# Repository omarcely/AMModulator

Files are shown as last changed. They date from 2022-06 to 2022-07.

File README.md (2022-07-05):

# AMModulator
Final RF circuits' project of Omar Cely, Diego Figueroa and Felipe González

## Resultados 

A continuación se puede observar el transmisor AM, y observar los resultados del circuito implementado en cada una de las etapas de interés.

## transmisor AM

En el montaje final se observa principalmente la antena, cuyo diametro es de 44 cm y tiene 3 vueltas, además se ve la pequeña placa que implementa el oscilador y el mezclador que mide 5cm x 2.5cm.

WhatsApp Image 2022-07-05 at 17 14 21

### Salida del oscilador

salida del oscilador medida con el analizador de espectros, como se puede ver se tiene una frecuencia de oscilación de 27.6 MHz aproximadamente, sin embargo la frecuencoa es ajustable por medio del inductor variable utilizado.

WhatsApp Image 2022-07-05 at 17 06 35

### Salida del mezclador

salida del mezcaldor medida con un analizador de espectros, y teniendo como mensaje una señal de 15kHz, como resultado se observa la portadora, y varios armónicos del mensaje en las bandas lateralres, podria ser bueno utilizar un filtro pasa bandas para mejorar el desempeño del mezclador

WhatsApp Image 2022-07-05 at 17 08 02

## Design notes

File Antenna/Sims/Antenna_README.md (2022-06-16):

# AMModulator
Final RF circuits' project of Omar Cely, Diego Figueroa and Felipe González

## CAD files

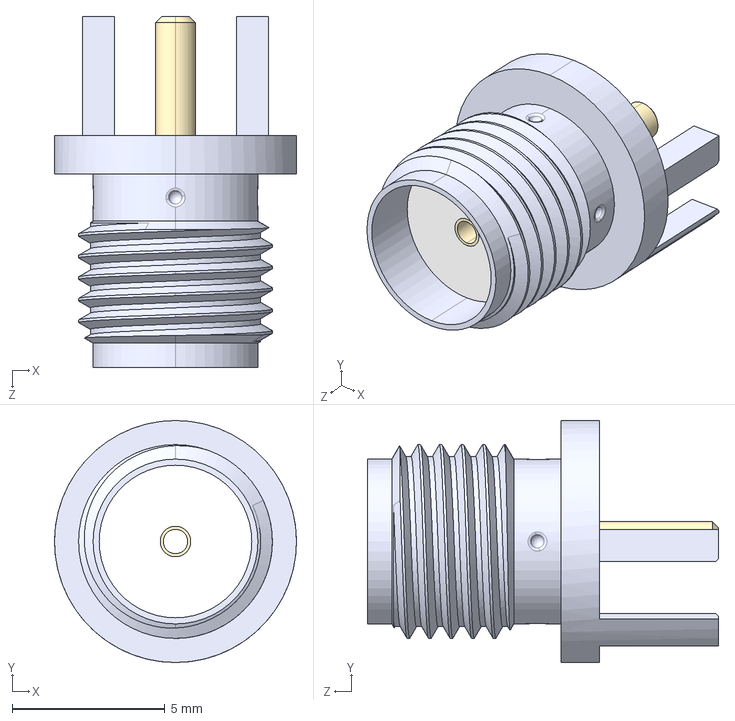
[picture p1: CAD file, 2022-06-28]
PCB design/AM_modulator/SMA/CONSMA003.062/CONSMA003.062.step
7.93 x 7.93 x 11.5 mm

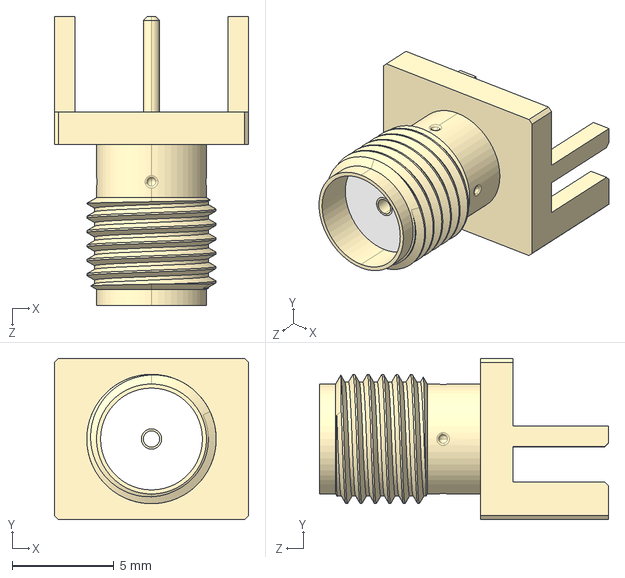
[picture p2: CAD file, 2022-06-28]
PCB design/AM_modulator/SMA/SMA/CONSMA020.062-G.step
9.52 x 7.92 x 14.2 mm

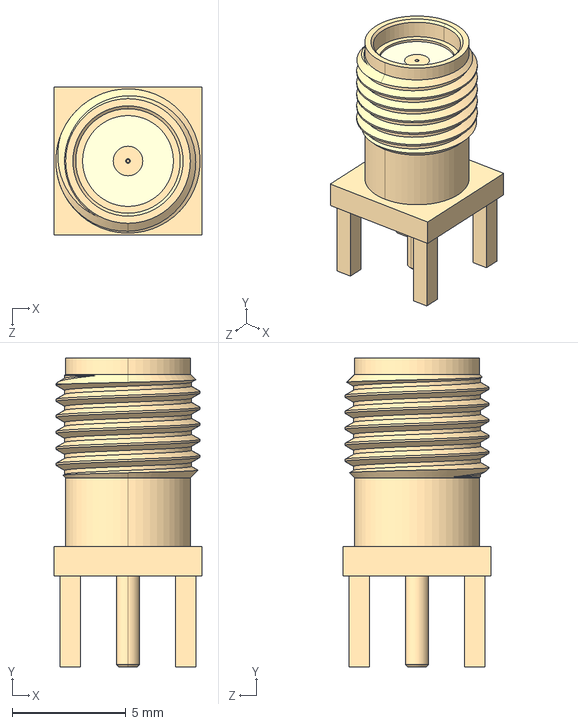
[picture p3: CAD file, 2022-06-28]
PCB design/AM_modulator/SMA/SMA_2/SMA_CONNECTOR.step
6.50 x 13.6 x 6.50 mm

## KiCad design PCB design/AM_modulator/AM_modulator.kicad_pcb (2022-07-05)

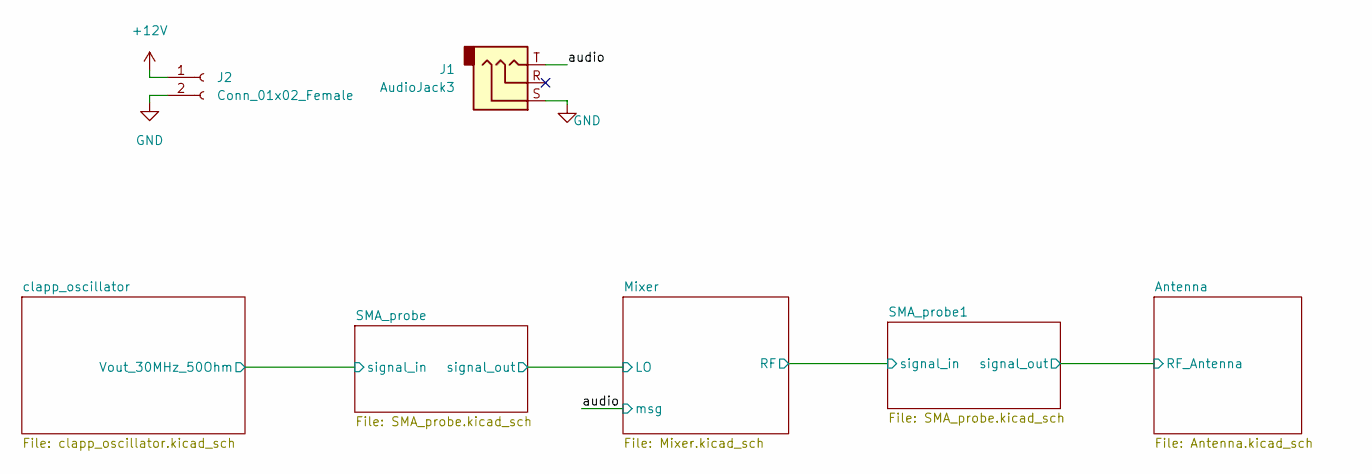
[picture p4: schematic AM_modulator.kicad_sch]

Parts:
J1: AudioJack3; Jack_Sigma
J2: Conn_01x02_Female; PinSocket_1x02_P2.54mm_Vertical

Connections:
+12V: J2.1; also elsewhere on the board
/audio: J1.T; also elsewhere on the board
GND: J1.S, J2.2; also elsewhere on the board

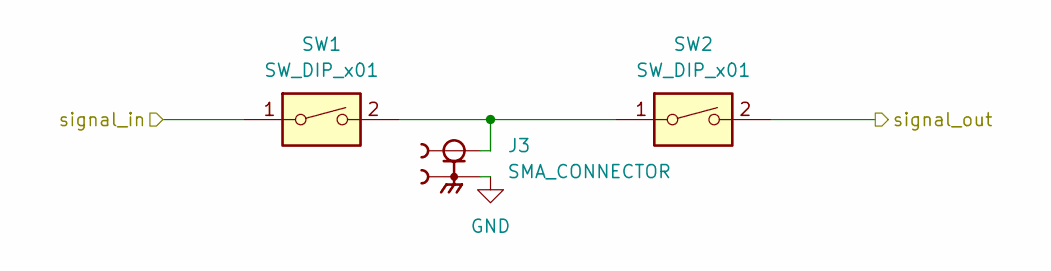
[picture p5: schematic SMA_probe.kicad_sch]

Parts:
J3: SMA_CONNECTOR; LPRS_SMA_CONNECTOR; PARTREV 1.3
SW1, SW2: SW_DIP_x01; R_1206_3216Metric

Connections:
/Mixer/LO: SW2.2; also elsewhere on the board
/SMA_probe/signal_in: SW1.1; also elsewhere on the board
GND: J3.G1, J3.G2, J3.G3, J3.G4; also elsewhere on the board
unnamed: J3.1, SW1.2, SW2.1

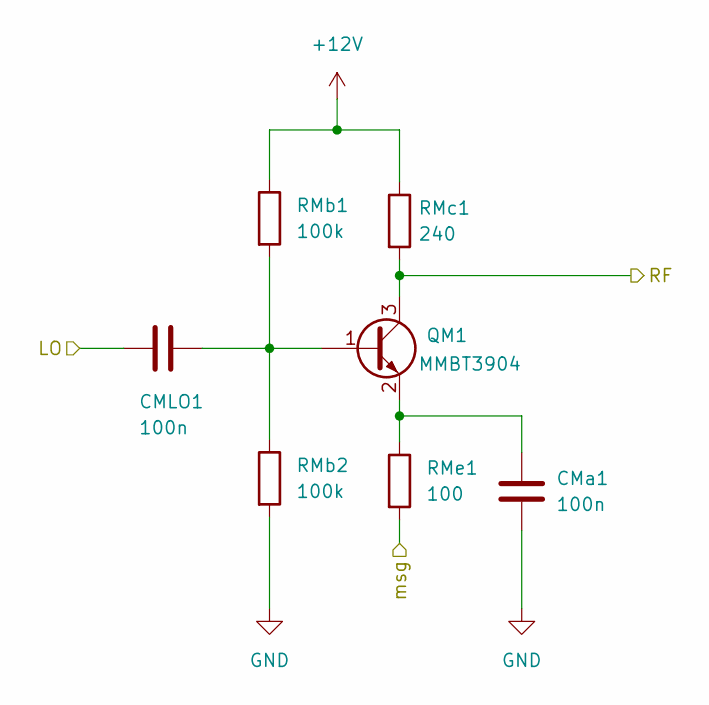
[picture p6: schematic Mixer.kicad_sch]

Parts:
CMLO1: 100n; C_0805_2012Metric_Pad1.18x1.45mm_HandSolder
CMa1: 100n; C_0805_2012Metric_Pad1.18x1.45mm_HandSolder
QM1: MMBT3904; SOT-23
RMb1, RMb2: 100k; R_1206_3216Metric_Pad1.30x1.75mm_HandSolder
RMc1: 240; R_1206_3216Metric_Pad1.30x1.75mm_HandSolder
RMe1: 100; R_1206_3216Metric_Pad1.30x1.75mm_HandSolder

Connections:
+12V: RMb1.1, RMc1.1; also elsewhere on the board
/Mixer/LO: CMLO1.2; also elsewhere on the board
/Mixer/RF: QM1.3 (C), RMc1.2; also elsewhere on the board
/audio: RMe1.2; also elsewhere on the board
GND: CMa1.2, RMb2.2; also elsewhere on the board
unnamed: CMLO1.1, QM1.1 (B), RMb1.2, RMb2.1
unnamed: CMa1.1, QM1.2 (E), RMe1.1

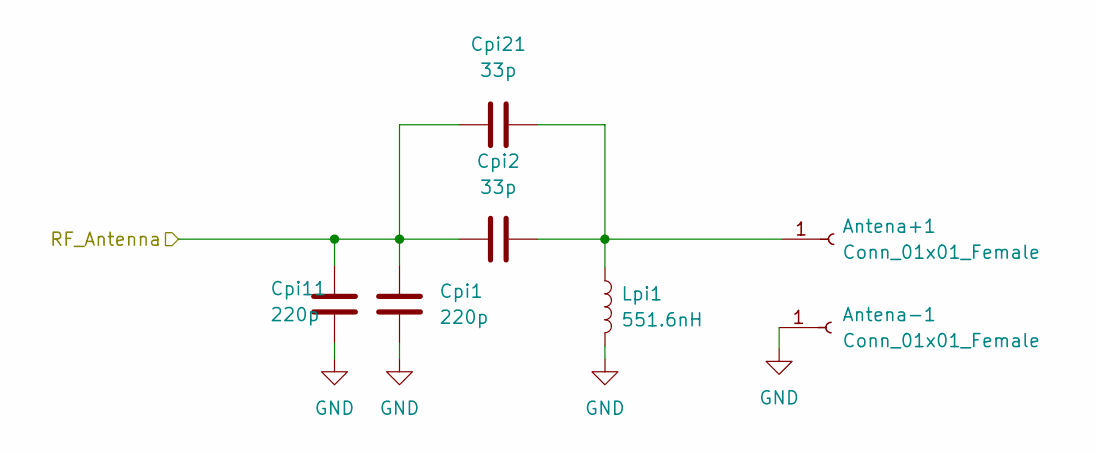
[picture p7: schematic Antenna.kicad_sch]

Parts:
Antena+1: Conn_01x01_Female; Pin_D1.4mm_L8.5mm_W2.8mm_FlatFork
Antena-1: Conn_01x01_Female; Pin_D1.4mm_L8.5mm_W2.8mm_FlatFork
Cpi1, Cpi11: 220p; C_0805_2012Metric_Pad1.18x1.45mm_HandSolder
Cpi2, Cpi21: 33p; C_0805_2012Metric_Pad1.18x1.45mm_HandSolder
Lpi1: 551.6nH; L_Toroid_Vertical_L21.6mm_W9.1mm_P8.40mm_Bourns_5700

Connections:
/Antenna/RF_Antenna: Cpi1.1, Cpi2.1, Cpi11.2, Cpi21.1; also elsewhere on the board
GND: Antena-1.1, Cpi1.2, Cpi11.1, Lpi1.2; also elsewhere on the board
unnamed: Antena+1.1, Cpi2.2, Cpi21.2, Lpi1.1

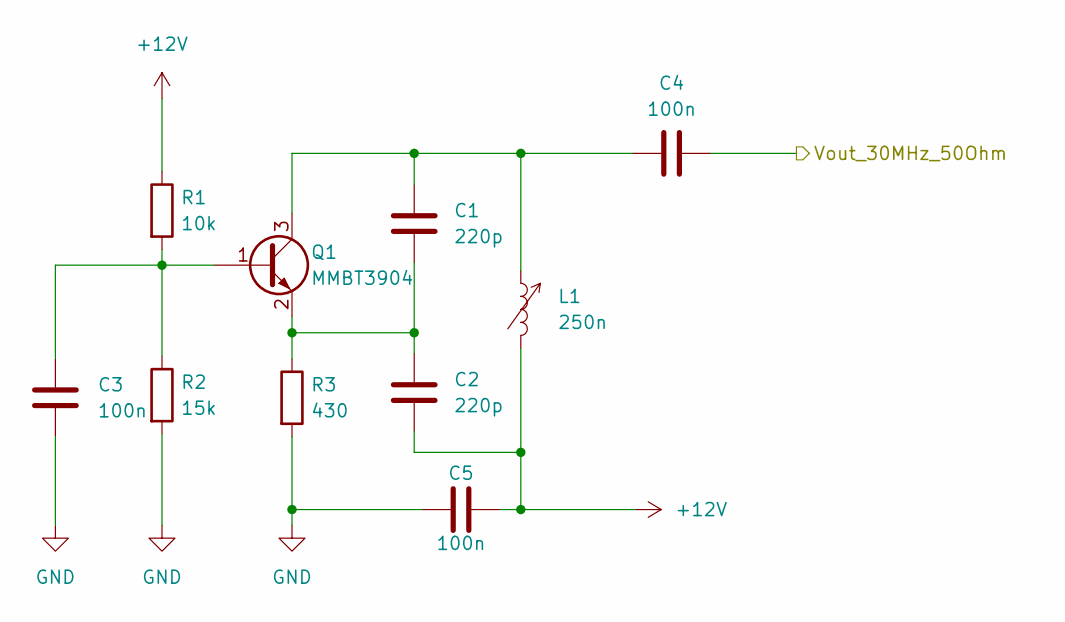
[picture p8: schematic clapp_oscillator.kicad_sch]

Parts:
C1, C2: 220p; C_0805_2012Metric_Pad1.18x1.45mm_HandSolder
C3, C4, C5: 100n; C_0805_2012Metric_Pad1.18x1.45mm_HandSolder
L1: 250n; variable_inductor
Q1: MMBT3904; SOT-23
R1: 10k; R_1206_3216Metric_Pad1.30x1.75mm_HandSolder
R2: 15k; R_1206_3216Metric_Pad1.30x1.75mm_HandSolder
R3: 430; R_1206_3216Metric_Pad1.30x1.75mm_HandSolder

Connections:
+12V: C2.2, C5.2, L1.2, R1.1; also elsewhere on the board
/SMA_probe/signal_in: C4.2; also elsewhere on the board
GND: C3.2, C5.1, R2.2, R3.2; also elsewhere on the board
unnamed: C1.1, C4.1, L1.1, Q1.3 (C)
unnamed: C1.2, C2.1, Q1.2 (E), R3.1
unnamed: C3.1, Q1.1 (B), R1.2, R2.1

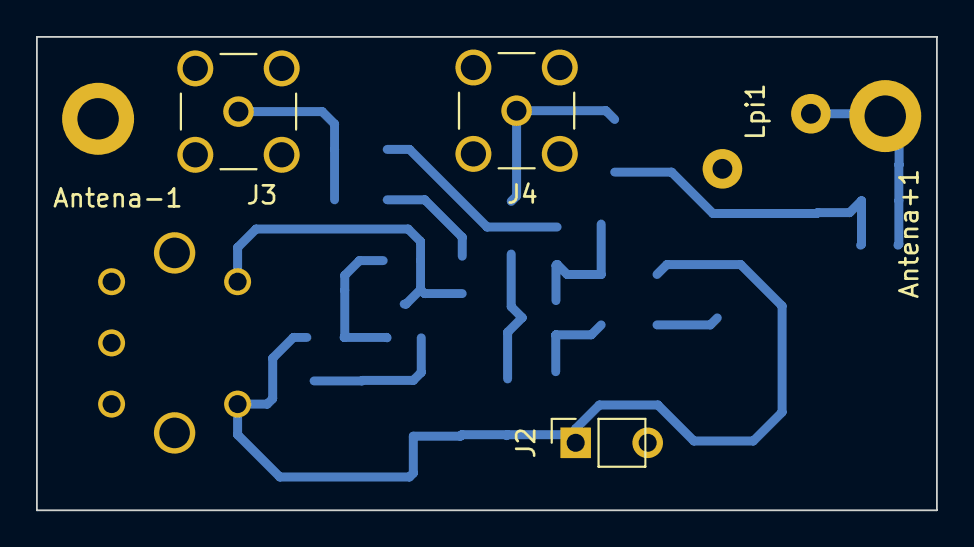
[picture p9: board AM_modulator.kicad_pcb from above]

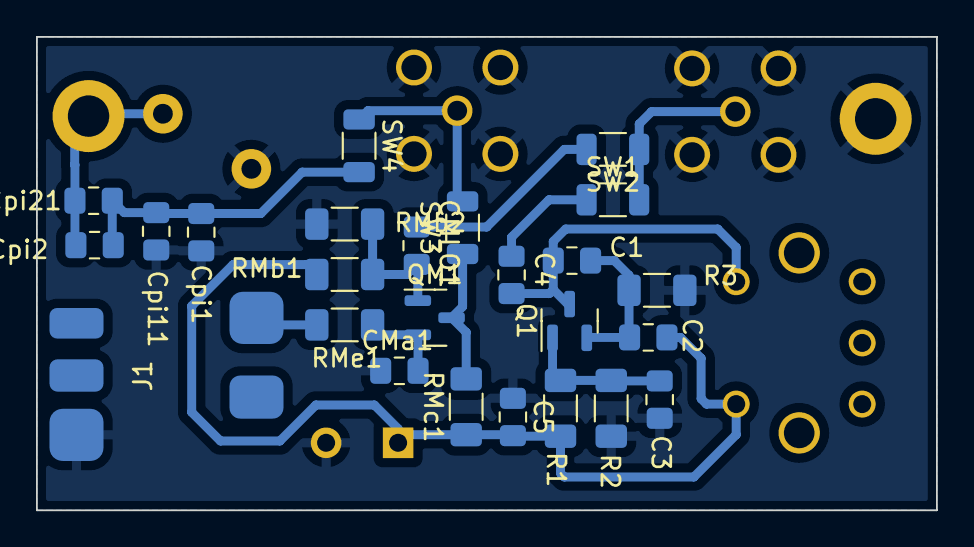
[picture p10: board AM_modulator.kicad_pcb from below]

Board: 2 copper layers, 50.0 x 26.3 mm, 32 parts (25 on the bottom side), 15 nets.

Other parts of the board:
J4: SMA_CONNECTOR; LPRS_SMA_CONNECTOR
SW3, SW4: SW_DIP_x01; R_1206_3216Metric

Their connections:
/Antenna/RF_Antenna: SW4.2; also elsewhere on the board
/Mixer/RF: SW3.1; also elsewhere on the board
GND: J4.G1, J4.G2, J4.G3, J4.G4; also elsewhere on the board
unnamed: J4.1, SW3.2, SW4.1

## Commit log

2022-06-20 begin of PCB design -- oscillator
    [AM_modulator.kicad_pcb, AM_modulator.kicad_sch, clapp_oscillator.kicad_sch]
2022-06-20 oscillator PCB design done
    [AM_modulator.kicad_pcb]
2022-06-22 Mixer
    Con BJT y entrada por la base
2022-06-28 Mixer en la placa
    Integración del mezclador en la placa
    [AM_modulator.kicad_sch, Antenna.kicad_sch, Mixer.kicad_sch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]
2022-06-28 Nothing useful
    [AM_modulator.kicad_sch, Antenna.kicad_sch]
2022-06-28 Avances placa
    [AM_modulator.kicad_pcb, AM_modulator.kicad_sch, Antenna.kicad_sch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]
2022-06-28 Antenna march sim
2022-06-28 Antenna Match with practical values
2022-06-28 Antenna matching script uploaded
2022-06-28 Placa terminada
    [AM_modulator.kicad_pcb, AM_modulator.kicad_sch, Antenna.kicad_sch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]
2022-06-29 PCB 2.0
    [AM_modulator.kicad_pcb, AM_modulator.kicad_sch, Mixer.kicad_sch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]
2022-06-30 "Just updated the Antenna sim"
2022-07-01 PCB design done
    [AM_modulator.kicad_pcb, AM_modulator.kicad_sch, Antenna.kicad_sch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]
2022-07-05 PCB corregida
    [AM_modulator-B_Cu.gbr, AM_modulator-B_Mask.gbr, AM_modulator-B_Paste.gbr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]
